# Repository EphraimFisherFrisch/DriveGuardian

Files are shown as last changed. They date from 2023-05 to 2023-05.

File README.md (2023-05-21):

# Drive Guardian
The Drive Guardian is a device created by 3 high-school sophomores, Brian Jackson, Ephraim Fisher, and Natan Dov Segal. The purpose of the device is to keep teenage drivers and their passengers safe by not allowing them to violate teen driving laws.

## Iterations

Originally, our first sketch of our prototype included a CO<sub>2</sub> detector in order to detect when the engine was on or off. When we originally showed our idea to Adam Jerozolim, our CIJE mentor, he suggested that we use a piezo sensor instead to detect whether on not the engine was on. We orginally tried to use a single 9V battery instead of a 6x AA battery pack, but we realized that that did not produce enough current. Also, we had originally developed the project on an Arduino Uno instead of a Nano, but we changed this to a Nano in order to save space.

## Components
* 3x [Pressure Sensors](https://www.amazon.com/SENSING-RESISTOR-SQUARE-1oz-22LBS-SPACING/dp/B00B887DBC/) ($15.53 each; $46.59 total)
* 1x [Piezo Sensor](https://www.amazon.com/MakerHawk-Analog-Ceramic-Vibration-Arduino/dp/B07KS5NV4V) ($1.50)
* 1x [Servo](https://www.amazon.com/Micro-Helicopter-Airplane-Remote-Control/dp/B072V529YD) ($1.88)
* 1x Arduino Nano (Any ATMega328-based Arduino should work) ($5.75)
* 1x NodeMCU ($7.99)
* 3x 10k Ohm Resistors ($0.03)
* 6x AA Battery Pack ($2.99)
* 6x AA Batteries 

**Total Cost: $66.73**

## Circuit Setup
DriveGuardian

The components should be wired as follows:
| Component | Arduino Nano |
| --- | ---- |
| Pressure Sensor | A0 |
| Pressure Sensor | A1 |
| Pressure Sensor | A2 |
| Piezo Sensor | A3 |
| Servo | D5 |

The Arduino Nano should be wired to the NodeMCU as follows:
| Arduino Nano | NodeMCU | Description |
| ---- | --- | --- |
| D2 | D6 | Data line for servo status |
| D8 | D1 | Data line for first pressure sensor |
| D9 | D2 | Data line for second pressure sensor |
| D10 | D3 | Data line for third pressure sensor |
| D11 | D5 | Data line for piezo sensor |

## Code

### Arduino Nano
The following libraries must be installed for the Arduino Nano:
* `Servo.h`

The following is a programming flowchart for the Arduino Nano code:

DriveGuardian Nano Flowchart

The following is a pseudocode demonstration of the Arduino Nano code:

```
Pressure Sensor One Input is A0
Pressure Sensor Two Input is A1
Pressure Sensor Three Input is A2
Piezo Sensor Input is A3
Configure servo on D5

Servo Data Line is D2
Pressure Sensor One Data Line is D8
Pressure Sensor Two Data Line is D9
Pressure Sensor Three Data Line is D10
Piezo Sensor Data Line is D11

Do once for setup:
  Configure all data lines except for the servo data line as output pins
  Configure the servo data line as an input pin
  Write initial low values to all data lines
  Set up the servo data line as an interrupt to trigger the following whenever it changes status:
    If the data line is high:
      Close the servo
    Else:
      Open the servo

Constantly loop through the following:
  Read pressure sensors and piezo sensor and update data lines accordingly
  Wait 20 ms
```

### NodeMCU
The following libraries must be installed for the NodeMCU:
* `ESP8266WiFi.h`
* `BlynkSimpleEsp8266.h`
* `ezTime.h`

The following is a programming flowchart for the NodeMCU code:

DriveGuardian NodeMCU Flowchart

The following is a pseudocode demonstration of the NodeMCU code:
```
Pressure Sensor One Data Line is D1
Pressure Sensor Two Data Line is D2
Pressure Sensor Three Data Line is D3
Piezo Sensor Data Line is D5
Servo Data Line is D6

Do once for setup:
  Configure all data lines except for the servo data line as input pins
  Configure servo data line as an output pin
  Connect to the Blynk servers
  
Do every second:
  Read data lines and update status of pressure sensors and piezo sensors on Blynk
  If DriveGuardian is in override mode:
    Set the servo data line to low
  Otherwise, if DriveGuardian is in lock mode:
    Set the servo data line to high if the piezo sensor is low, otherwise set it to low
  Otherwise, if it is past curfews imposed by law (11PM-5AM):
    Set the servo data line to high if the piezo sensor is low, otherwise set it to low
  Otherwise, if two or more pressure sensors are high:
    Set the servo data line to high if the piezo sensor is low, otherwise set it to low
  Otherwise, if a custom curfew is enabled:
    If it is during a time when the custom curfew would bar driving:
      Set the servo data line to high if the piezo sensor is low, otherwise set it to low
  If none of the above conditions are met:
    Set the servo data line to low
```

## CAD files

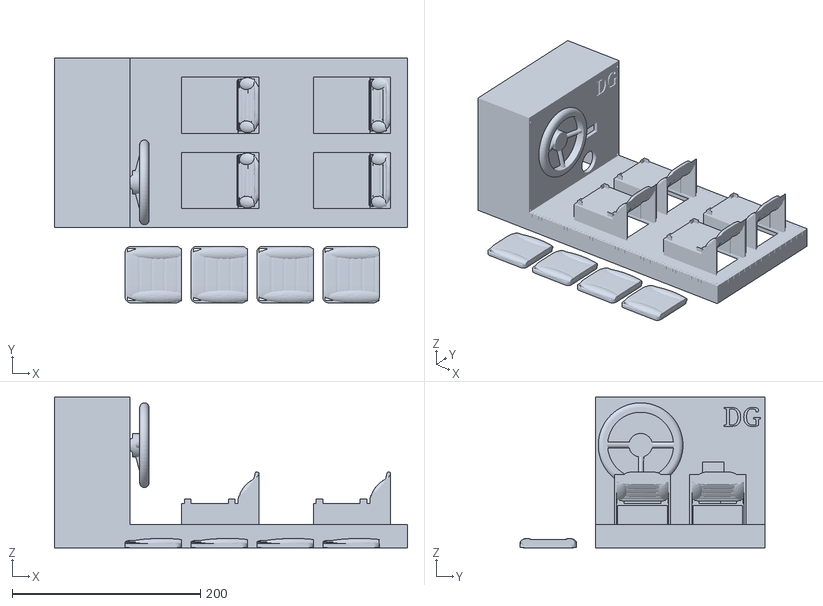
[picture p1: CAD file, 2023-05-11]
DriveGuardian CAD Model.stl
375.0 x 260.0 x 160.0

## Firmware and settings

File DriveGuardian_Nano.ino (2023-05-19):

#include <Servo.h>

#define SEAT_ONE_PIN A0
#define SEAT_TWO_PIN  A1
#define SEAT_THREE_PIN A2
#define PIEZO_PIN A3
#define SEAT_ONE_OUT 8
#define SEAT_TWO_OUT 9
#define SEAT_THREE_OUT 10
#define PIEZO_OUT 11

#define SERVO_INTERRUPT_PIN 2
#define SERVO_PIN 5
#define SERVO_CLOSE_VALUE 10
#define SERVO_OPEN_VALUE 120

//#define DG_DB // Uncomment this line to enable Serial prints for debugging

Servo servo;
volatile bool servoStatus;

// Converts analogRead of pressure sensor to a boolean True if above a certain threshold
bool seatStatus(char pin) {
  if (analogRead(pin) < 15) {
    return false;
  }
  // Get a second reading after a 1ms delay to eliminate incorrect noise readings
  delay(1);
  if (analogRead(pin) < 15) {
    return false;
  }
  return true;
}

// Converts analogRead of piezo sensor to a boolean True if above a certain threshold
bool piezoStatus(char pin) {
  if (analogRead(pin) < 15) {
    return false;
  }
  // Get a second reading after a 1ms delay to eliminate incorrect noise readings
  delay(1);
  if (analogRead(pin) < 15) {
    return false;
  }
  return true;
}

// Handles receiving signals from NodeMCU regarding the servo
void updateServo() {
  #ifdef DG_DB
  Serial.print("INT ");
  Serial.println(digitalRead(2));
  #endif

  // If the Nano is receiving a HIGH signal from the NodeMCU, set the servoStatus to close
  if (digitalRead(2) == HIGH) {
    servoStatus = true;
  } else { // If it is receiving a LOW signal, set servoStatus to stay open
    servoStatus = false;
  }
}

void setup() {
  #ifdef DG_DB
  Serial.begin(9600);
  #endif

  pinMode(SEAT_ONE_OUT, OUTPUT);
  pinMode(SEAT_TWO_OUT, OUTPUT);
  pinMode(SEAT_THREE_OUT, OUTPUT);
  pinMode(PIEZO_OUT, OUTPUT);
  pinMode(SERVO_INTERRUPT_PIN, INPUT);
  servo.attach(SERVO_PIN);

  digitalWrite(SEAT_ONE_OUT, LOW);
  digitalWrite(SEAT_TWO_OUT, LOW);
  digitalWrite(SEAT_THREE_OUT, LOW);
  digitalWrite(PIEZO_OUT, LOW);
  servo.write(SERVO_OPEN_VALUE);

  // Call updateServo() whenever the pin receiving the instructions for the servo from NodeMCU changes
  attachInterrupt(digitalPinToInterrupt(SERVO_INTERRUPT_PIN), updateServo, CHANGE);
}

void loop() {
  #ifdef DG_DB
  Serial.print("Seat One: ");
  Serial.print(seatStatus(SEAT_ONE_PIN));
  Serial.print(" ");
  Serial.println(analogRead(SEAT_ONE_PIN));
  Serial.print("Seat Two: ");
  Serial.print(seatStatus(SEAT_TWO_PIN));
  Serial.print(" ");
  Serial.println(analogRead(SEAT_TWO_PIN));
  Serial.print("Seat Three: ");
  Serial.print(seatStatus(SEAT_THREE_PIN));
  Serial.print(" ");
  Serial.println(analogRead(SEAT_THREE_PIN));
  Serial.print("Piezo: ");
  Serial.print(piezoStatus(PIEZO_PIN));
  Serial.print(" ");
  Serial.println(analogRead(PIEZO_PIN));
  #endif

  // Actualize the changes made in updateServo()
  if (servoStatus) {
    servo.write(SERVO_CLOSE_VALUE);
  } else {
    servo.write(SERVO_OPEN_VALUE);
  }

  // Send data to NodeMCU for handling
  digitalWrite(SEAT_ONE_OUT, seatStatus(SEAT_ONE_PIN));
  digitalWrite(SEAT_TWO_OUT, seatStatus(SEAT_TWO_PIN));
  digitalWrite(SEAT_THREE_OUT, seatStatus(SEAT_THREE_PIN));
  digitalWrite(PIEZO_OUT, piezoStatus(PIEZO_PIN));
  #ifdef DG_DB
  delay(1000);
  #else
  delay(20);
  #endif
}

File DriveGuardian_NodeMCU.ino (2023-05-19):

#define BLYNK_TEMPLATE_ID           "TMPLcFCd6rvo"
#define BLYNK_TEMPLATE_NAME         "DriveGuardian"
#define BLYNK_AUTH_TOKEN            "pfhjRGldoeS36w5NO_e4kSj5G5e_HG4p"
#define BLYNK_PRINT Serial

#include <ESP8266WiFi.h>
#include <BlynkSimpleEsp8266.h>
#include <ezTime.h>

#define SEAT_ONE_IN 5
#define SEAT_TWO_IN 4
#define SEAT_THREE_IN 0
#define PIEZO_IN 14
#define SERVO_STATUS_OUT 12

//#define DG_DB // Uncomment this line to enable Serial prints for debugging

char ssid[] = "iPhoneEphraim";
char pass[] = "ephraimhotspot";

BlynkTimer timer;
Timezone timeObject;
char settingStatus;

bool customCurfew;
char ccStartHour;
char ccStartMinute;
char ccStopHour;
char ccStopMinute;

// Called when connected to the Blynk server
BLYNK_CONNECTED() {
  // Get the current UTC time
  Blynk.sendInternal("utc", "time");
  Blynk.syncAll();
}

BLYNK_WRITE(InternalPinUTC) {
  // Pass the current UTC time into the ezTime library
  const uint64_t utc_time = param[1].asLongLong();
  UTC.setTime(utc_time / 1000, utc_time % 1000);
}

// Called whenever the settings are changed from Blynk
BLYNK_WRITE(V0) {
  #ifdef DG_DB
  Serial.print("settingStatus changed to: ");
  Serial.println(param.asInt());
  #endif

  settingStatus = param.asInt();
}

// Update custom curfew and timezone when modified
BLYNK_WRITE(V2) {
  TimeInputParam t(param);

  ccStartHour = t.getStartHour();
  ccStartMinute = t.getStartMinute();
  ccStopHour = t.getStopHour();
  ccStopMinute = t.getStopMinute();
  timeObject.setLocation(t.getTZ());
}

BLYNK_WRITE(V3) {
  customCurfew = param.asInt();
}

bool servoStatus() {
  // If in override mode, keep the servo open
  if (settingStatus == 2) {
    return false;
  } else if (settingStatus == 0) { // If in lock mode, turn off if the car is off
    return !digitalRead(PIEZO_IN);
  } else { // When in normal functionality check for time and pressure sensor restrictions
    if (timeObject.hour() >= 23 || timeObject.hour() <= 4) {
      return !digitalRead(PIEZO_IN);
    } else if (digitalRead(SEAT_ONE_IN) + digitalRead(SEAT_TWO_IN) + digitalRead(SEAT_THREE_IN) > 1) {
      return !digitalRead(PIEZO_IN);
    } else if (customCurfew) {
      if ((timeObject.hour() < ccStartHour || (timeObject.hour() == ccStartHour && timeObject.minute() < ccStartMinute)) || (timeObject.hour() > ccStopHour) || (timeObject.hour() == ccStopHour && timeObject.minute() >= ccStopMinute)) {
        return !digitalRead(PIEZO_IN);
      }
    }
    return false;
  }
}

void everySecond() {
  #ifdef DG_DB
  Serial.print("Seat One: ");
  Serial.println(digitalRead(SEAT_ONE_IN));
  Serial.print("Seat Two: ");
  Serial.println(digitalRead(SEAT_TWO_IN));
  Serial.print("Seat Three: ");
  Serial.println(digitalRead(SEAT_THREE_IN));
  Serial.print("Piezo: ");
  Serial.println(digitalRead(PIEZO_IN));
  #endif

  // Send data received from Nano to Blynk
  Blynk.virtualWrite(V4, digitalRead(SEAT_ONE_IN));
  Blynk.virtualWrite(V5, digitalRead(SEAT_TWO_IN));
  Blynk.virtualWrite(V6, digitalRead(SEAT_THREE_IN));
  Blynk.virtualWrite(V1, digitalRead(PIEZO_IN));

  // Send instruction to Nano to open or close servo
  digitalWrite(SERVO_STATUS_OUT, servoStatus());
  #ifdef DG_DB
  Serial.println("Servo status: " + String(servoStatus()));
  #endif
}

void setup() {
  #ifdef DG_DB
  Serial.begin(9600);
  #endif

  pinMode(SEAT_ONE_IN, INPUT);
  pinMode(SEAT_TWO_IN, INPUT);
  pinMode(SEAT_THREE_IN, INPUT);
  pinMode(PIEZO_IN, INPUT);
  pinMode(LED_BUILTIN, OUTPUT);
  pinMode(SERVO_STATUS_OUT, OUTPUT);
  
  digitalWrite(SERVO_STATUS_OUT, LOW); // Send initial instruction to Nano to keep the servo open
  digitalWrite(LED_BUILTIN, HIGH); // Turn built-in LED off

  Blynk.begin(BLYNK_AUTH_TOKEN, ssid, pass); // Connect to Blynk
  digitalWrite(LED_BUILTIN, LOW); // Turn built-in LED on once connected to Blynk

  // Set up a timer to call everySecond() every second
  timer.setInterval(1000L, everySecond);

  // Set up time zone
  timeObject.setLocation("America/New_York");
}

void loop() {
  Blynk.run();
  timer.run();
}
